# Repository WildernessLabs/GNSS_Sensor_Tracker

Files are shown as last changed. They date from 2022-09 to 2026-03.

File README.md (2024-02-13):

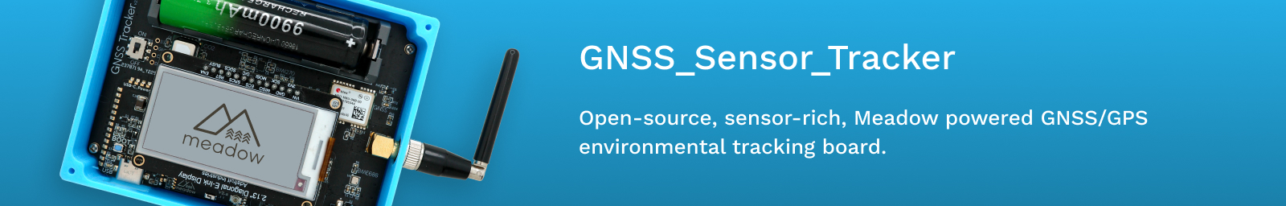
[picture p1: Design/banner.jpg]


# GNSS_Sensor_Tracker

The GNSS Sensor Tracker is an open-source, sensor-rich, GNSS/GPS tracking board intended to provide a base design accelerator for custom Meadow-based GNSS tracking solutions.

## Contents
* [Purchasing or Building](#purchasing-or-building)
* [Getting Started](#getting-started)
* [Hardware Specifications](#hardware-specifications)
* [Video Stream Design Series](#video-stream-design-series)
* [Industrial Enclosure Design](#industrial-enclosure-design)

## Purchasing or Building

<table width="100%">
    <tr>
        <td>
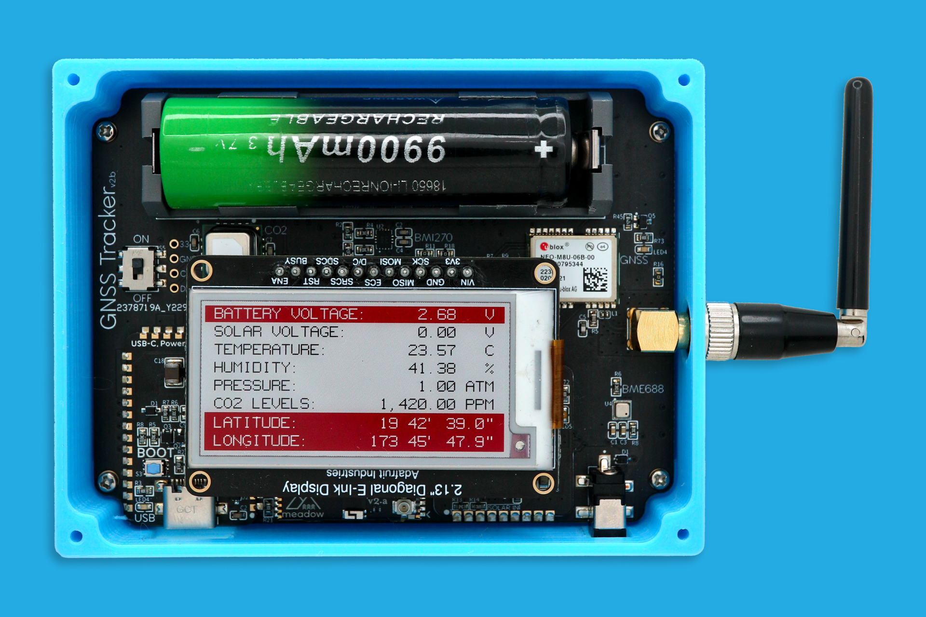
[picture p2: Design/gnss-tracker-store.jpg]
            
        </td>
        <td>
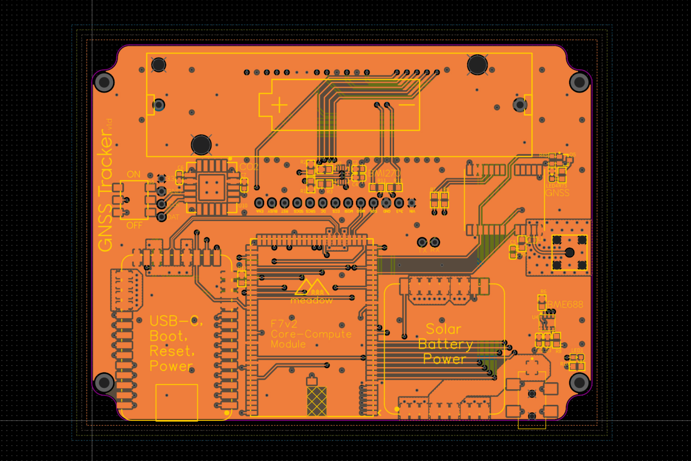
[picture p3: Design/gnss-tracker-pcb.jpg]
             
        </td>
    </tr>
    <tr>
        <td>
            You can get a Gnss Sensor Tracker fully assembled from the <a href="https://store.wildernesslabs.co/collections/frontpage/products/gnss-sensor-tracker">Wilderness Labs store</a>.
        </td>
        <td> 
            It's also designed so that it can be assembled at home for the adventurous. All design files can be found in the <a href="Hardware/Design%20Files/">Hardware Design</a> folder.
        </td>
    </tr>
</table>

## Getting Started

To simplify the way to use this Meadow-powered reference IoT product, we've created a NuGet package that instantiates and encapsulates the onboard hardware into a `GnssTracker` class.

1. Add the ProjectLab Nuget package your project: 
    - `dotnet add package Meadow.GnssTracker`, or
    - [Meadow.GnssTracker Nuget Package](https://www.nuget.org/packages/Meadow.GnssTracker)
    - [Explore in Fuget.org](https://www.fuget.org/packages/Meadow.GnssTracker/0.96.0/lib/netstandard2.1/GnssTracker.dll/WildernessLabs.Hardware.GnssTracker/GnssTracker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)

2. Instantiate the `IGnssTrackerHardware` object:  
```csharp
public class MeadowApp : App<F7CoreComputeV2>
{
    IGnssTrackerHardware gnssTracker;

    public override Task Initialize()
    {
        gnssTracker = GnssTracker.Create();
        ...
```

3. To Access the `GNSS Tracker` onboard peripherals (Display, for example):
```csharp
    if (gnssTracker.Display is { } display)
    {
        microGraphics = new MicroGraphics(display);
        microGraphics.Clear();
        microGraphics.DrawText(10, 10, "Hello World");
        microGraphics.Show();
    }
```

## Hardware Specifications

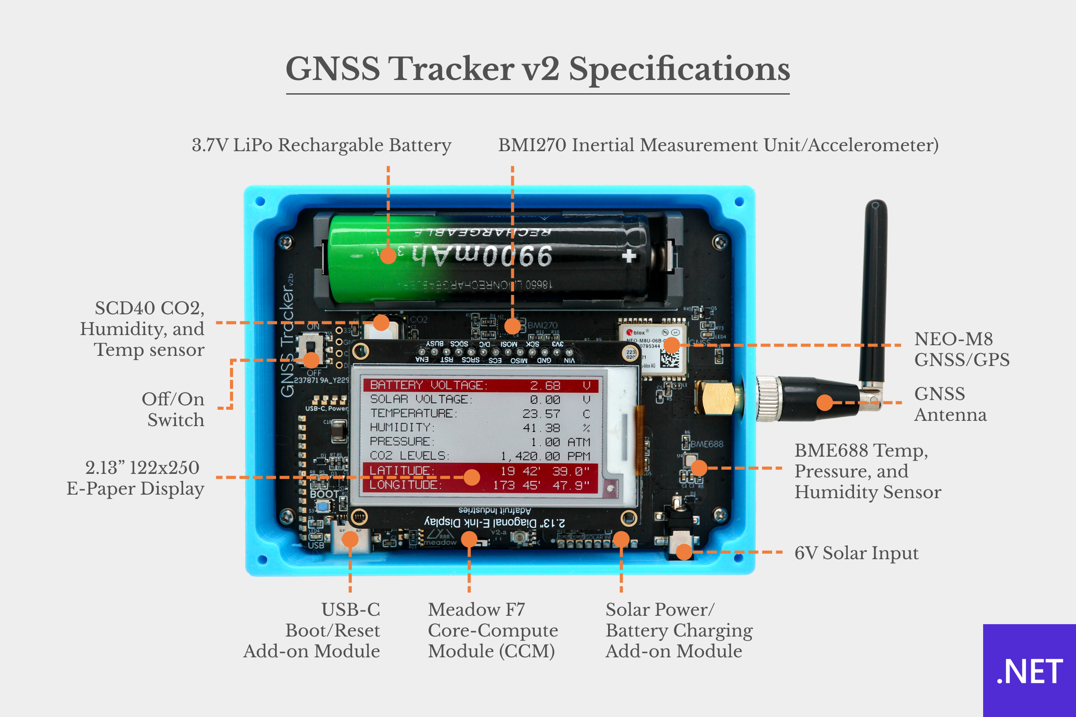
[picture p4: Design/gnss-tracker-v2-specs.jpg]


<table>
    <tr>
        <td><strong>3.7V LiPo Rechargeable Battery</strong></td>
        <td><strong>BMI270 Inertial Measurement Unit / Accelerometer</strong></td>
    </tr>
    <tr>
        <td><strong>SCD40 CO2, Humidity and Temperature sensor</strong></td>
        <td><strong>Off/On Switch</strong></td>
    </tr>
    <tr>
        <td><strong>SSD1680 122x250 Adafruit E-Paper Display</strong></td>
        <td><strong>USB-C, Boot, Reset Add-on Module</strong></td>
    </tr>
    <tr>
        <td><strong>Meadow F7 Core-Compute Module (CCM)</strong></td>
        <td><strong>Solar Power/Battery Charging Add-on Module</strong></td>
    </tr>
    <tr>
        <td><strong>6V Solar Input Connector</strong></td>
        <td><strong>BME688 Temp, Pressure and Humidity sensor</strong></td>
    </tr>
    <tr>
        <td><strong>GNSS/GPS Antenna</strong></td>
        <td><strong>NEO-M8 GNSS/GPS</strong></td>
    </tr>
</table>

You can find the schematics and other design files in the [Hardware folder](Hardware/Design%20Files/).

## Video Stream Design Series

This board was designed while streaming live, you can watch the videos [here](https://www.youtube.com/watch?v=L4MavM8ilkg&list=PLoP9Fu9zn7qY4rkFJjHBhnpI8mPlw8RfS).

<a href="https://www.youtube.com/watch?v=L4MavM8ilkg&list=PLoP9Fu9zn7qY4rkFJjHBhnpI8mPlw8RfS">
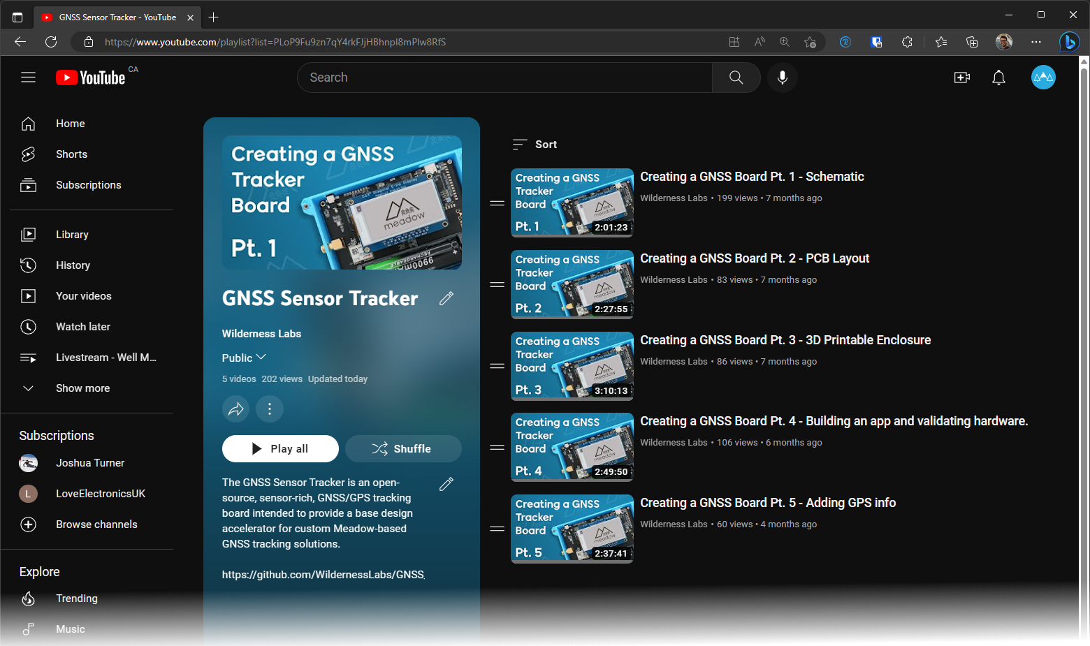
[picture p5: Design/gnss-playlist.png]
    
</a>

## Industrial Enclosure Design

The enclosure was designed in Autodesk Fusion 360. The source file can be found and STL files can be found [here](Hardware/Enclosure/).

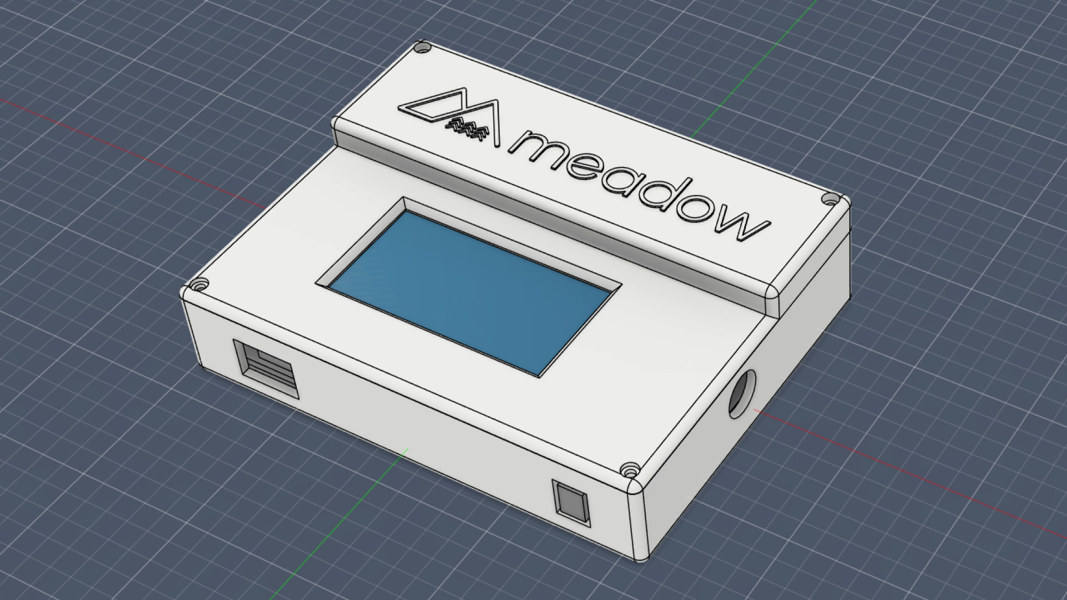
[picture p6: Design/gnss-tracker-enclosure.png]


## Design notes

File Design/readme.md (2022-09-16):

# Docs

This board was prototyped using the [Addon Modules](https://github.com/WildernessLabs/Hardware_Addon_Modules) we created to shorten hardware design time.

## Schematic 



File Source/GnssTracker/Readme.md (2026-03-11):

# Meadow.GnssTracker

**Convenience library for the Meadow GNSS Sensor Tracker**

The **GnssTracker** library is included in the **Meadow.GnssTracker** nuget package and is designed for the [Wilderness Labs](www.wildernesslabs.co) Meadow .NET IoT platform.

The GNSS Sensor Tracker is an open-source, sensor-rich, GNSS/GPS tracking board that provides a base design accelerator for custom Meadow-based GNSS tracking solutions.

For more information on developing for Meadow, visit [developer.wildernesslabs.co](http://developer.wildernesslabs.co/).

To view all Wilderness Labs open-source projects, including samples, visit [github.com/wildernesslabs](https://github.com/wildernesslabs/).

## Onboard Hardware

| Peripheral | Description |
|---|---|
| NEO-M8 | GNSS/GPS module with antenna connector |
| SSD1680 | 122x250 e-paper display |
| BME688 | Temperature, pressure, humidity, and gas resistance sensor |
| SCD40 | CO2, humidity, and temperature sensor |
| BMI270 | Inertial measurement unit / accelerometer |
| RGB LED | Onboard status LED |
| Solar input | 6V solar connector with battery charging |
| Battery | 3.7V LiPo rechargeable battery |

## Installation

You can install the library from within Visual Studio using the NuGet Package Manager or from the command line using the .NET CLI:

`dotnet add package Meadow.GnssTracker`

## Usage

```csharp
public class MeadowApp : App<F7CoreComputeV2>
{
    IGnssTrackerHardware gnssTracker;

    public override Task Initialize()
    {
        gnssTracker = GnssTracker.Create();

        if (gnssTracker.TemperatureSensor is { } temperatureSensor)
        {
            temperatureSensor.Updated += (s, e) =>
                Resolver.Log.Info($"Temperature: {e.New.Celsius:N1}C");
        }

        if (gnssTracker.Gnss is { } gnss)
        {
            gnss.RmcReceived += (s, e) =>
            {
                if (e.IsValid)
                    Resolver.Log.Info($"GNSS: LAT [{e.Position.Latitude}], LONG [{e.Position.Longitude}]");
            };
        }

        if (gnssTracker.Display is { } display)
        {
            var graphics = new MicroGraphics(display);
            graphics.DrawText(10, 10, "Hello, GNSS Tracker!");
            graphics.Show();
        }

        if (gnssTracker.OnboardRgbLed is { } led)
        {
            led.StartPulse(Color.Green);
        }

        return Task.CompletedTask;
    }

    public override async Task Run()
    {
        if (gnssTracker.TemperatureSensor is { } temperatureSensor)
            temperatureSensor.StartUpdating(TimeSpan.FromMinutes(5));

        if (gnssTracker.Gnss is { } gnss)
            gnss.StartUpdating();

        await Task.Delay(Timeout.Infinite);
    }
}
```

## How to Contribute

- **Found a bug?** [Report an issue](https://github.com/WildernessLabs/Meadow_Issues/issues)
- Have a **feature idea or driver request?** [Open a new feature request](https://github.com/WildernessLabs/Meadow_Issues/issues)
- Want to **contribute code?** Fork the [GNSS_Sensor_Tracker](https://github.com/WildernessLabs/GNSS_Sensor_Tracker) repository and submit a pull request against the `develop` branch

## Need Help?

If you have questions or need assistance, please join the Wilderness Labs [community on Slack](http://slackinvite.wildernesslabs.co/).

## About Meadow

Meadow is a complete, IoT platform with defense-grade security that runs full .NET applications on embeddable microcontrollers and Linux single-board computers including Raspberry Pi and NVIDIA Jetson.

### Build

Use the full .NET platform and tooling such as Visual Studio and plug-and-play hardware drivers to painlessly build IoT solutions.

### Connect

Utilize native support for WiFi, Ethernet, and Cellular connectivity to send sensor data to the Cloud and remotely control your peripherals.

### Deploy

Instantly deploy and manage your fleet in the cloud for OtA, health-monitoring, logs, command + control, and enterprise backend integrations.

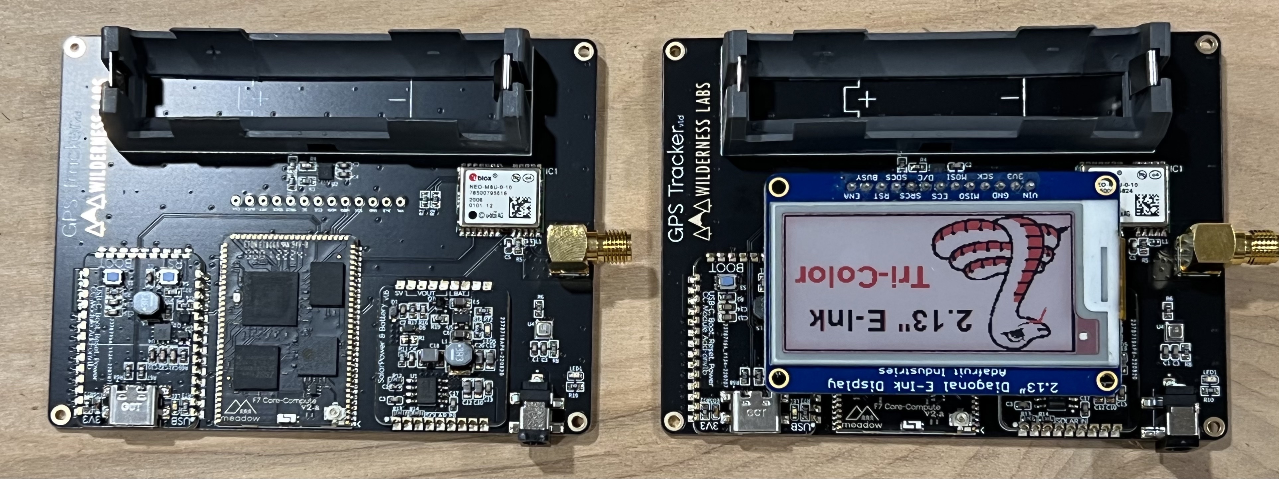
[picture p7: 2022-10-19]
Design/gnss-tracker-sides.jpg

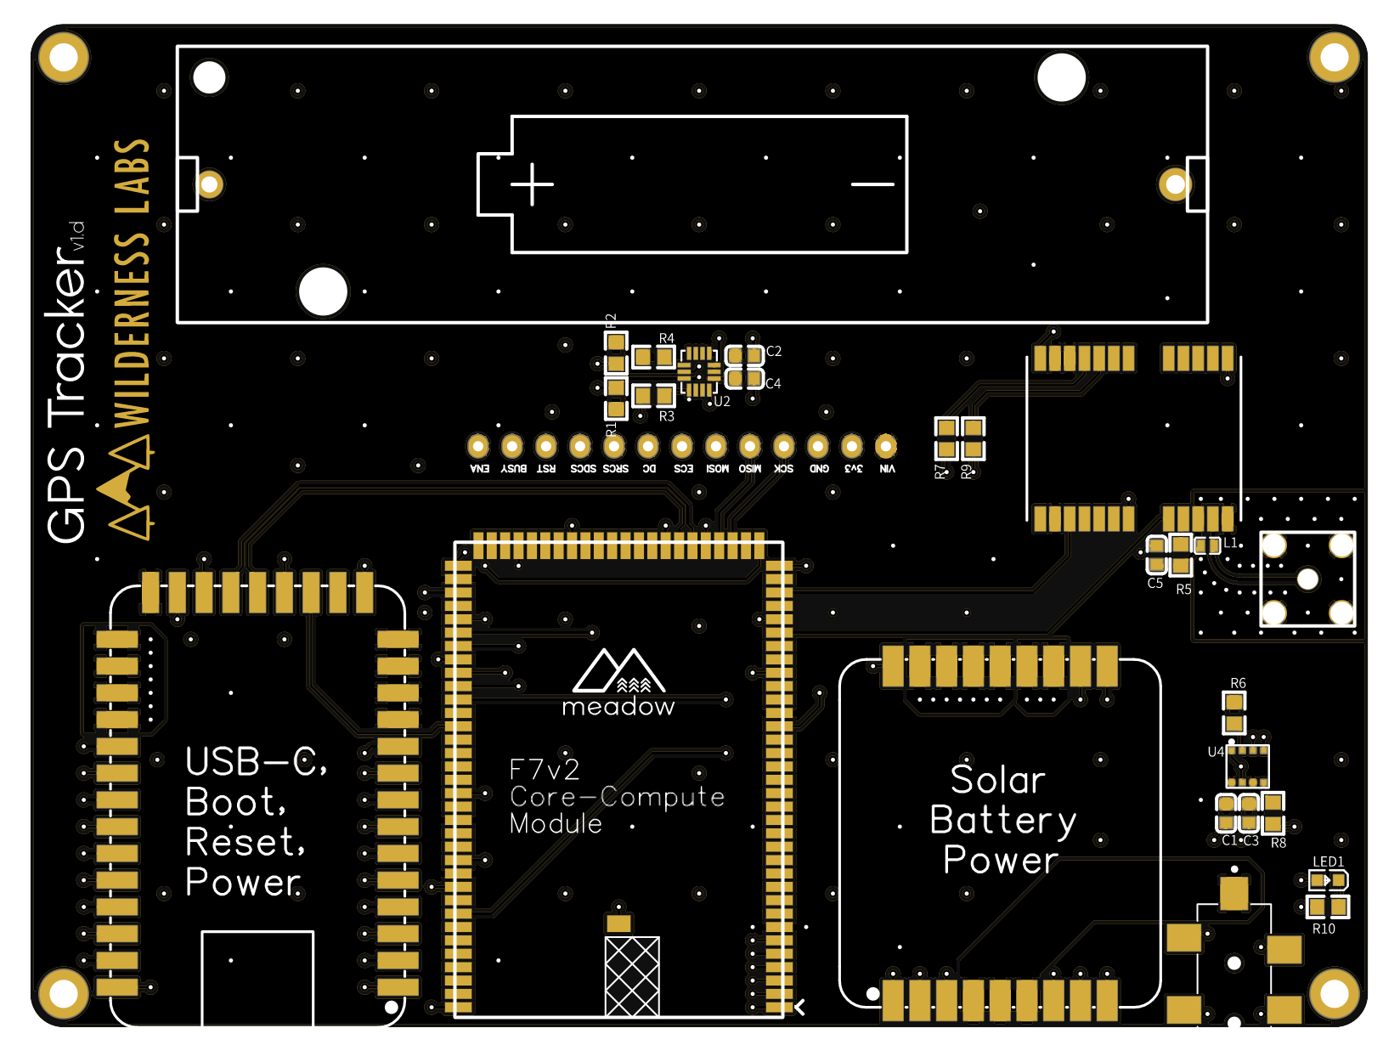
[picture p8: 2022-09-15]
Design/gnss-tracker-pcb-view.png

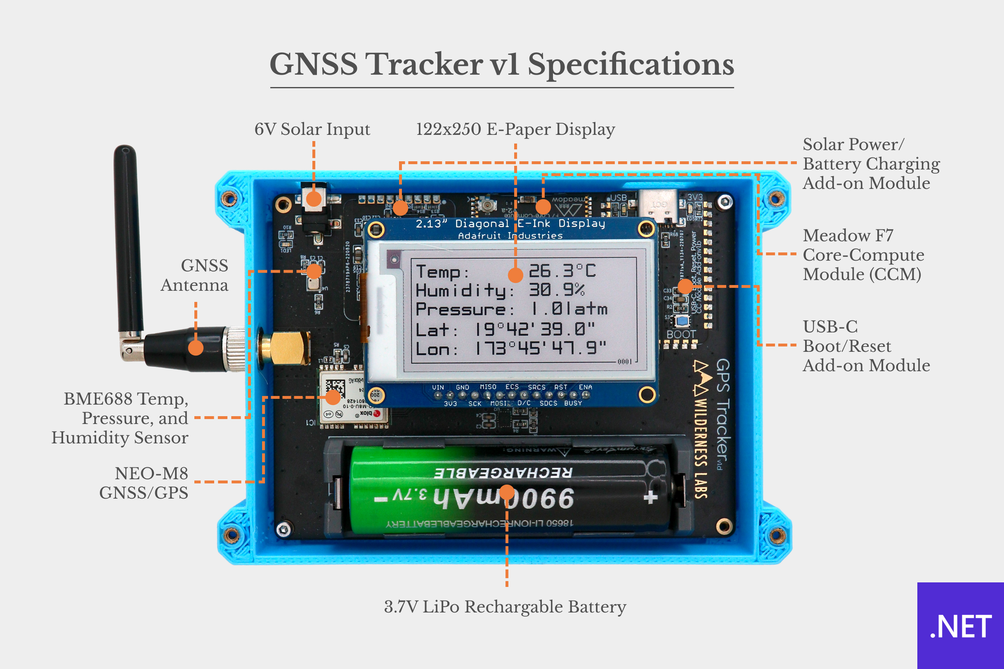
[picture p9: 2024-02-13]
Design/gnss-tracker-v1-specs.jpg

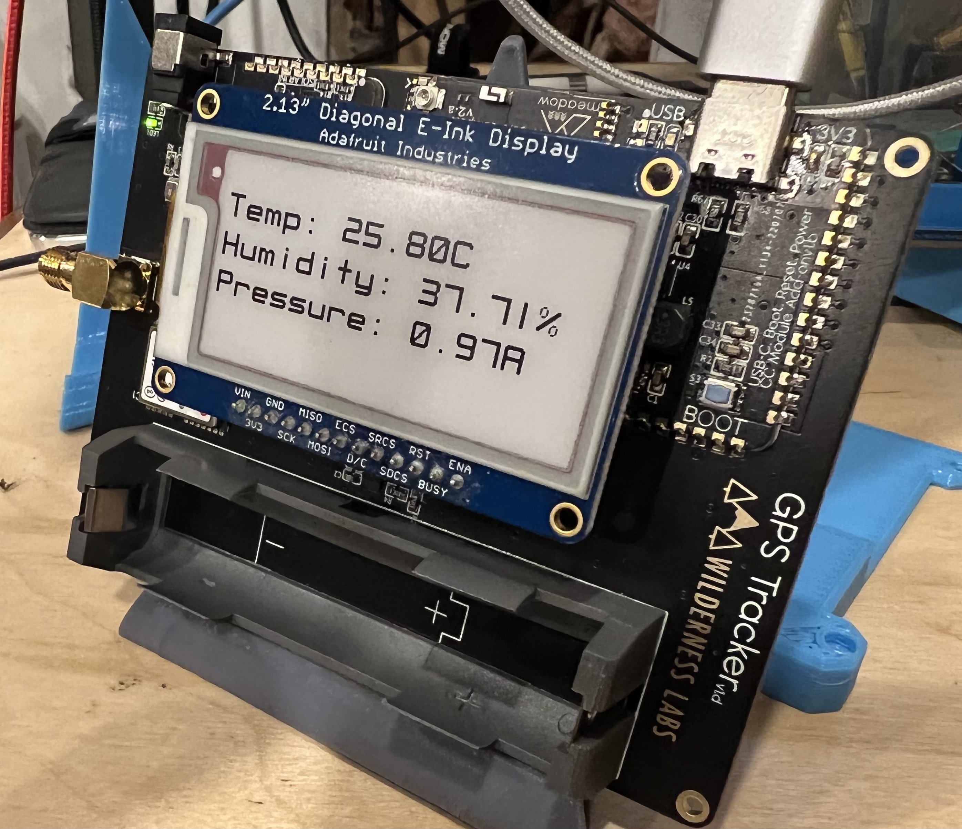
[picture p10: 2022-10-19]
Design/gnss-tracker-display.jpg

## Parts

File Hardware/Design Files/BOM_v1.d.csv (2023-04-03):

ID | Name | Designator | Footprint | Quantity | Manufacturer Part | Manufacturer | Supplier | Supplier Part | Price
1 | MEADOW F7 DEBUG ADDON MODULE | U15 | MEADOW F7 DEBUG ADDON MODULE | 1
2 | WILDERNESS_LABS_LOGO_HORIZONTAL | U9 | WILDERNESS_LABS_LOGO_HORIZONTAL | 1
3 | 0 | R12,R11,R18 | R0603 | 3 | RC0603JR-070RL | Yageo
4 | 1043P | U6 | BAT-TH_KEYSTONE-1043P | 1 | 1043P | Keystone | Digi-Key
5 | 452403012014 | S5 | 452403012014 | 1 | 452403012014 | Wurth Elektronik
6 | 470k | R45 | R0603 | 1 | RC0603FR-07470KL | Yageo
7 | EAST16083BA0 | LED4 | LED0603-RD | 1 | EAST16083BA0 | Everlight
8 | DMG1012UW-7 | Q5 | SOT-323-3_L2.2-W1.3-P1.30-LS2.1-BR | 1 | DMG1012UW-7 | Diodes Incorporated | LCSC | C156390 | 0.005
9 | 2k | R73,R10 | R0603 | 2 | RC0603FR-072KL | Yageo
10 | TESTPAD_PTH | TP1,TP2,TP3,TP4,TP5,TP6 | TESTPAD_PTH | 6
11 | 0.1u | C6,C7,C1,C2,C3,C4 | C0603 | 6 | CC0603KRX7R9BB103 | Yageo
12 | SCD40-D-R2 | U10 | LGA-20_L10.1-W10.1-P1.25-TL | 1 | SCD40-D-R2 | null | LCSC | C9900009940
13 | NEO-M8U | IC1 | NEO-M8U | 1
14 | ADAFRUIT_2.13_ePaper | U7 | ADAFRUIT 2.13 EINK 4197 (NO HOLES) | 1 | 4947 | Adafruit | Adafruit | 4947
15 | 47pF | C5 | C0603 | 1 | CC0603JRNPO9BN470 | Yageo
16 | PJ-030CH-SMT-TR | J1 | CUI_PJ-030CH-SMT-TR | 1
17 | 1kΩ | L1 | L0402 | 1 | BLM15HD102SN1D | MuRata | LCSC | C21516 | 0.001
18 | EAST1608GA0 | LED1 | LED0603-RD | 1 | EAST1608GA0 | Everlight
19 | 4.7k | R1,R2 | R0603 | 2 | RC0603JR-074K7L | Yageo
20 | 10k | R3,R4,R6,R8 | R0603 | 4 | RC0603FR-0710KL | Yageo
21 | 10Ω | R5 | R0603 | 1 | RC0603FR-0710RL | Yageo
22 | 220 | R7,R9 | R0603 | 2 | RC0603FR-07220RL | Yageo
23 | Meadow F7v2 Core-Compute Module - Logical | U1 | MEADOW_F7V2_CORE_COMPUTE | 1 |  | Wilderness Labs
24 | BMI270 | U2 | LGA-14_L3.0-W2.5-P0.50-BR | 1 | BMI270 | null | LCSC | C2836813 | 0.314
25 | Meadow Core-Compute USB-C, Power, Boot, and Reset Addon Module | U3 | MEADOW CORE-COMPUTE USB-C, POWER, BOOT, RESET ADDON MODULE | 1 |  | Wilderness Labs
26 | BME688 | U4 | LGA-8_L3.0-W3.0-P0.80-TR | 1 | BME688 | Bosch Sensortec
27 | 60311002114501 | U8 | SMA_60311002114501 | 1 | 60311002114501 | Wurth Elektronik | Adafruit
28 | Meadow Core-Compute Addon Module - Solar Battery Power | U5 | MEADOW CORE-COMPUTE SOLAR & BATTERY POWER ADDON MODULE | 1 |  | Wilderness Labs

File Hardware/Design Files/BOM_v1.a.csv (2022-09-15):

ID | Name | Designator | Footprint | Quantity | Manufacturer Part | Manufacturer | Supplier | Supplier Part | Price
1 | 0.1u | C1,C2,C3,C4 | C0603 | 4 | CC0603KRX7R9BB103 | Yageo
2 | 47pF | C5 | C0603 | 1 | CC0603JRNPO9BN470 | Yageo
3 | NEO-M8N | IC1 | NEO-M8U | 1
4 | PJ-030CH-SMT-TR | J1 | CUI_PJ-030CH-SMT-TR | 1
5 | 1kΩ | L1 | L0402 | 1 | BLM15HD102SN1D | MuRata | LCSC | C21516 | 0.009
6 | EAST1608GA0 | LED1 | LED0603-RD | 1 | EAST1608GA0 | Everlight
7 | 4.7k | R1,R2 | R0603 | 2 | RC0603JR-074K7L | Yageo
8 | 10k | R3,R4,R6,R8 | R0603 | 4 | RC0603FR-0710KL | Yageo
9 | 10Ω | R5 | R0603 | 1 | RC0603FR-0710RL | Yageo
10 | 220 | R7,R9 | R0603 | 2 | RC0603FR-07220RL | Yageo
11 | 2k | R10 | R0603 | 1 | RC0603FR-072KL | Yageo
12 | Meadow F7v2 Core-Compute Module - Logical | U1 | MEADOW_F7V2_CORE_COMPUTE | 1 |  | Wilderness Labs
13 | BMI270 | U2 | LGA-14_L3.0-W2.5-P0.50-BR | 1 | BMI270 | null | LCSC | C2836813 | 3.533
14 | Meadow Core-Compute USB-C, Power, Boot, and Reset Addon Module | U3 | MEADOW CORE-COMPUTE USB-C, POWER, BOOT, RESET ADDON MODULE | 1 |  | Wilderness Labs
15 | BME688 | U4 | LGA-8_L3.0-W3.0-P0.80-TR | 1 | BME688 | Bosch Sensortec
16 | Meadow Core-Compute Addon Module - Solar Battery Power | U5 | MEADOW CORE-COMPUTE SOLAR & BATTERY POWER ADDON MODULE | 1 |  | Wilderness Labs
17 | 1043P | U6 | BAT-TH_KEYSTONE-1043P | 1 | 1043P | Keystone | Digi-Key
18 | ADAFRUIT_2.13_ePaper | U7 | ADAFRUIT 2.13 EINK 4197 (NO HOLES) | 1 | 4947 | Adafruit | Adafruit | 4947
19 | 60311002114501 | U8 | SMA_60311002114501 | 1 | 60311002114501 | Wurth Elektronik | Adafruit
20 | WILDERNESS_LABS_LOGO_HORIZONTAL | U9 | WILDERNESS_LABS_LOGO_HORIZONTAL | 1

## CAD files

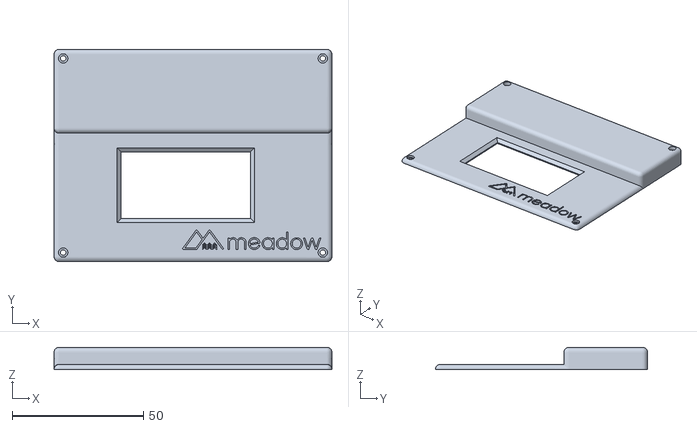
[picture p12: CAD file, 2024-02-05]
Hardware/Enclosure/GNSS_Enclosure_Top.stl
106.0 x 81.0 x 8.50

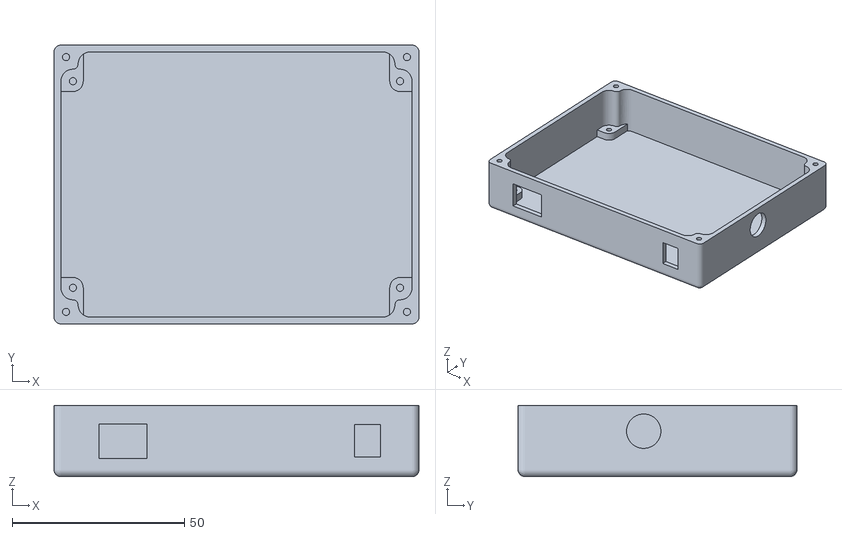
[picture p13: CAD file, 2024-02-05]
Hardware/Enclosure/GNSS_Enclosure_Bottom.stl
106.0 x 81.0 x 20.7

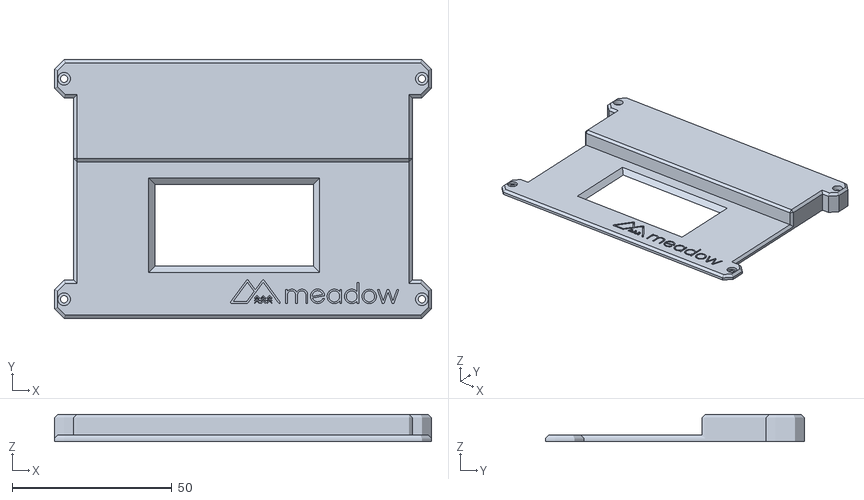
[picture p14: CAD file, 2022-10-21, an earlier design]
Hardware/Enclosure/Legacy/GNSS_Enclosure_Top.stl
118.0 x 81.0 x 8.50

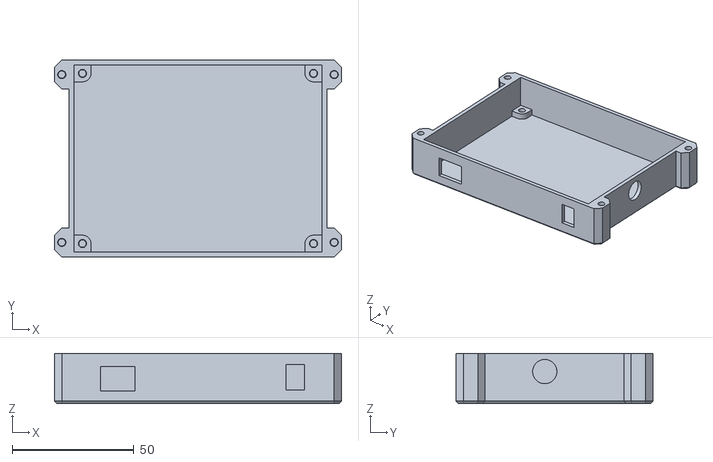
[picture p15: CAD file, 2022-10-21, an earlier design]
Hardware/Enclosure/Legacy/GNSS_Enclosure_Bottom.stl
118.0 x 81.0 x 20.7

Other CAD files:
Hardware/Enclosure/GNSS Sensor Tracker - Enclosure.f3d
Hardware/Enclosure/GNSS_Tracker_Enclosure.f3d
Hardware/Enclosure/Legacy/GNSS_Tracker_Enclosure.f3d

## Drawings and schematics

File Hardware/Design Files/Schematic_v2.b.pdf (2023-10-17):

## 0x77 - VDD

## 0x76 - GND

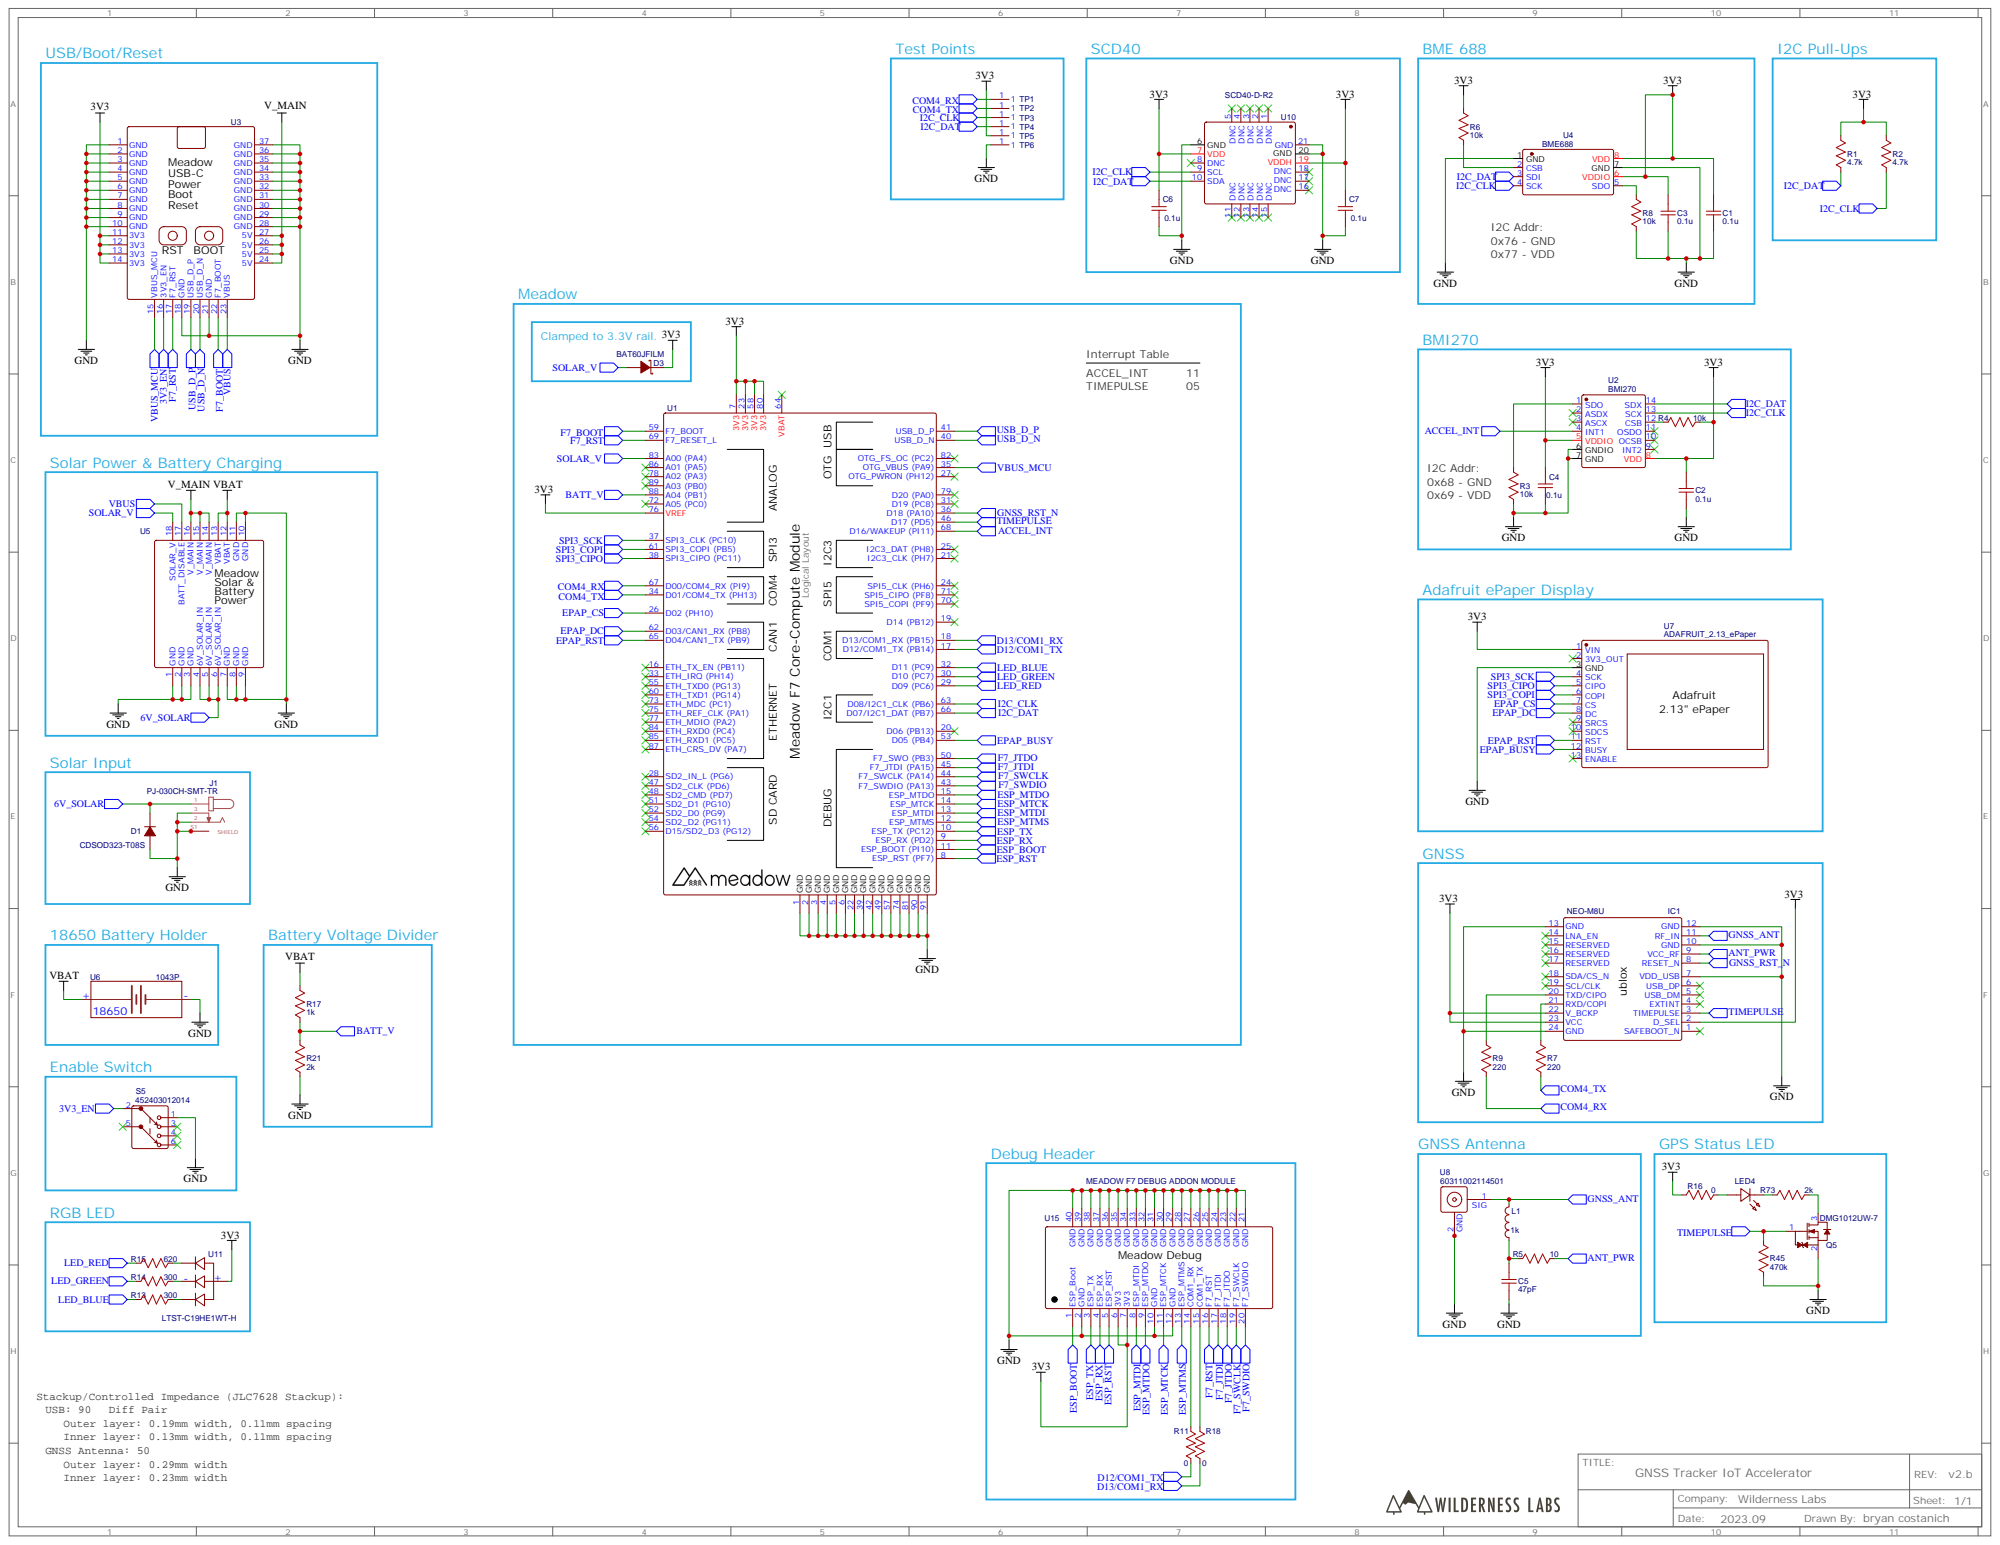
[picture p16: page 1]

5V 24 5V 25 5V 26 5V 27 GND 28 GND 29 GND 30 GND 31 GND 32 GND 33 GND 34 GND 35 GND 36 GND 37

Solar Power & Battery Charging

Meadow F7 Core-Compute Module

9 GND 10 GND 11 VBAT 12 VBAT 13 V_MAIN 14 V_MAIN 15 V_MAIN 16 BATT_DISABLE 17 SOLAR_V 18

MEADOW F7 DEBUG ADDON MODULE

F7_SWDIO 20 GND 21 GND 22 GND 23 GND 24 GND 25 GND 26 GND 27 GND 28 GND 29 GND 30 GND 31 GND 32 GND 33 GND 34 GND 35 GND 36 GND 37 GND 38 GND 39 GND 40

Stackup/Controlled Impedance (JLC7628 Stackup):
Outer layer: 0.19mm width, 0.11mm spacing
Inner layer: 0.13mm width, 0.11mm spacing
GNSS Antenna: 50
Outer layer: 0.29mm width
Inner layer: 0.23mm width

Drawn By: bryan costanich

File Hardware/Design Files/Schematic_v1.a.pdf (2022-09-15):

## 0x77 - VDD

## 0x76 - GND

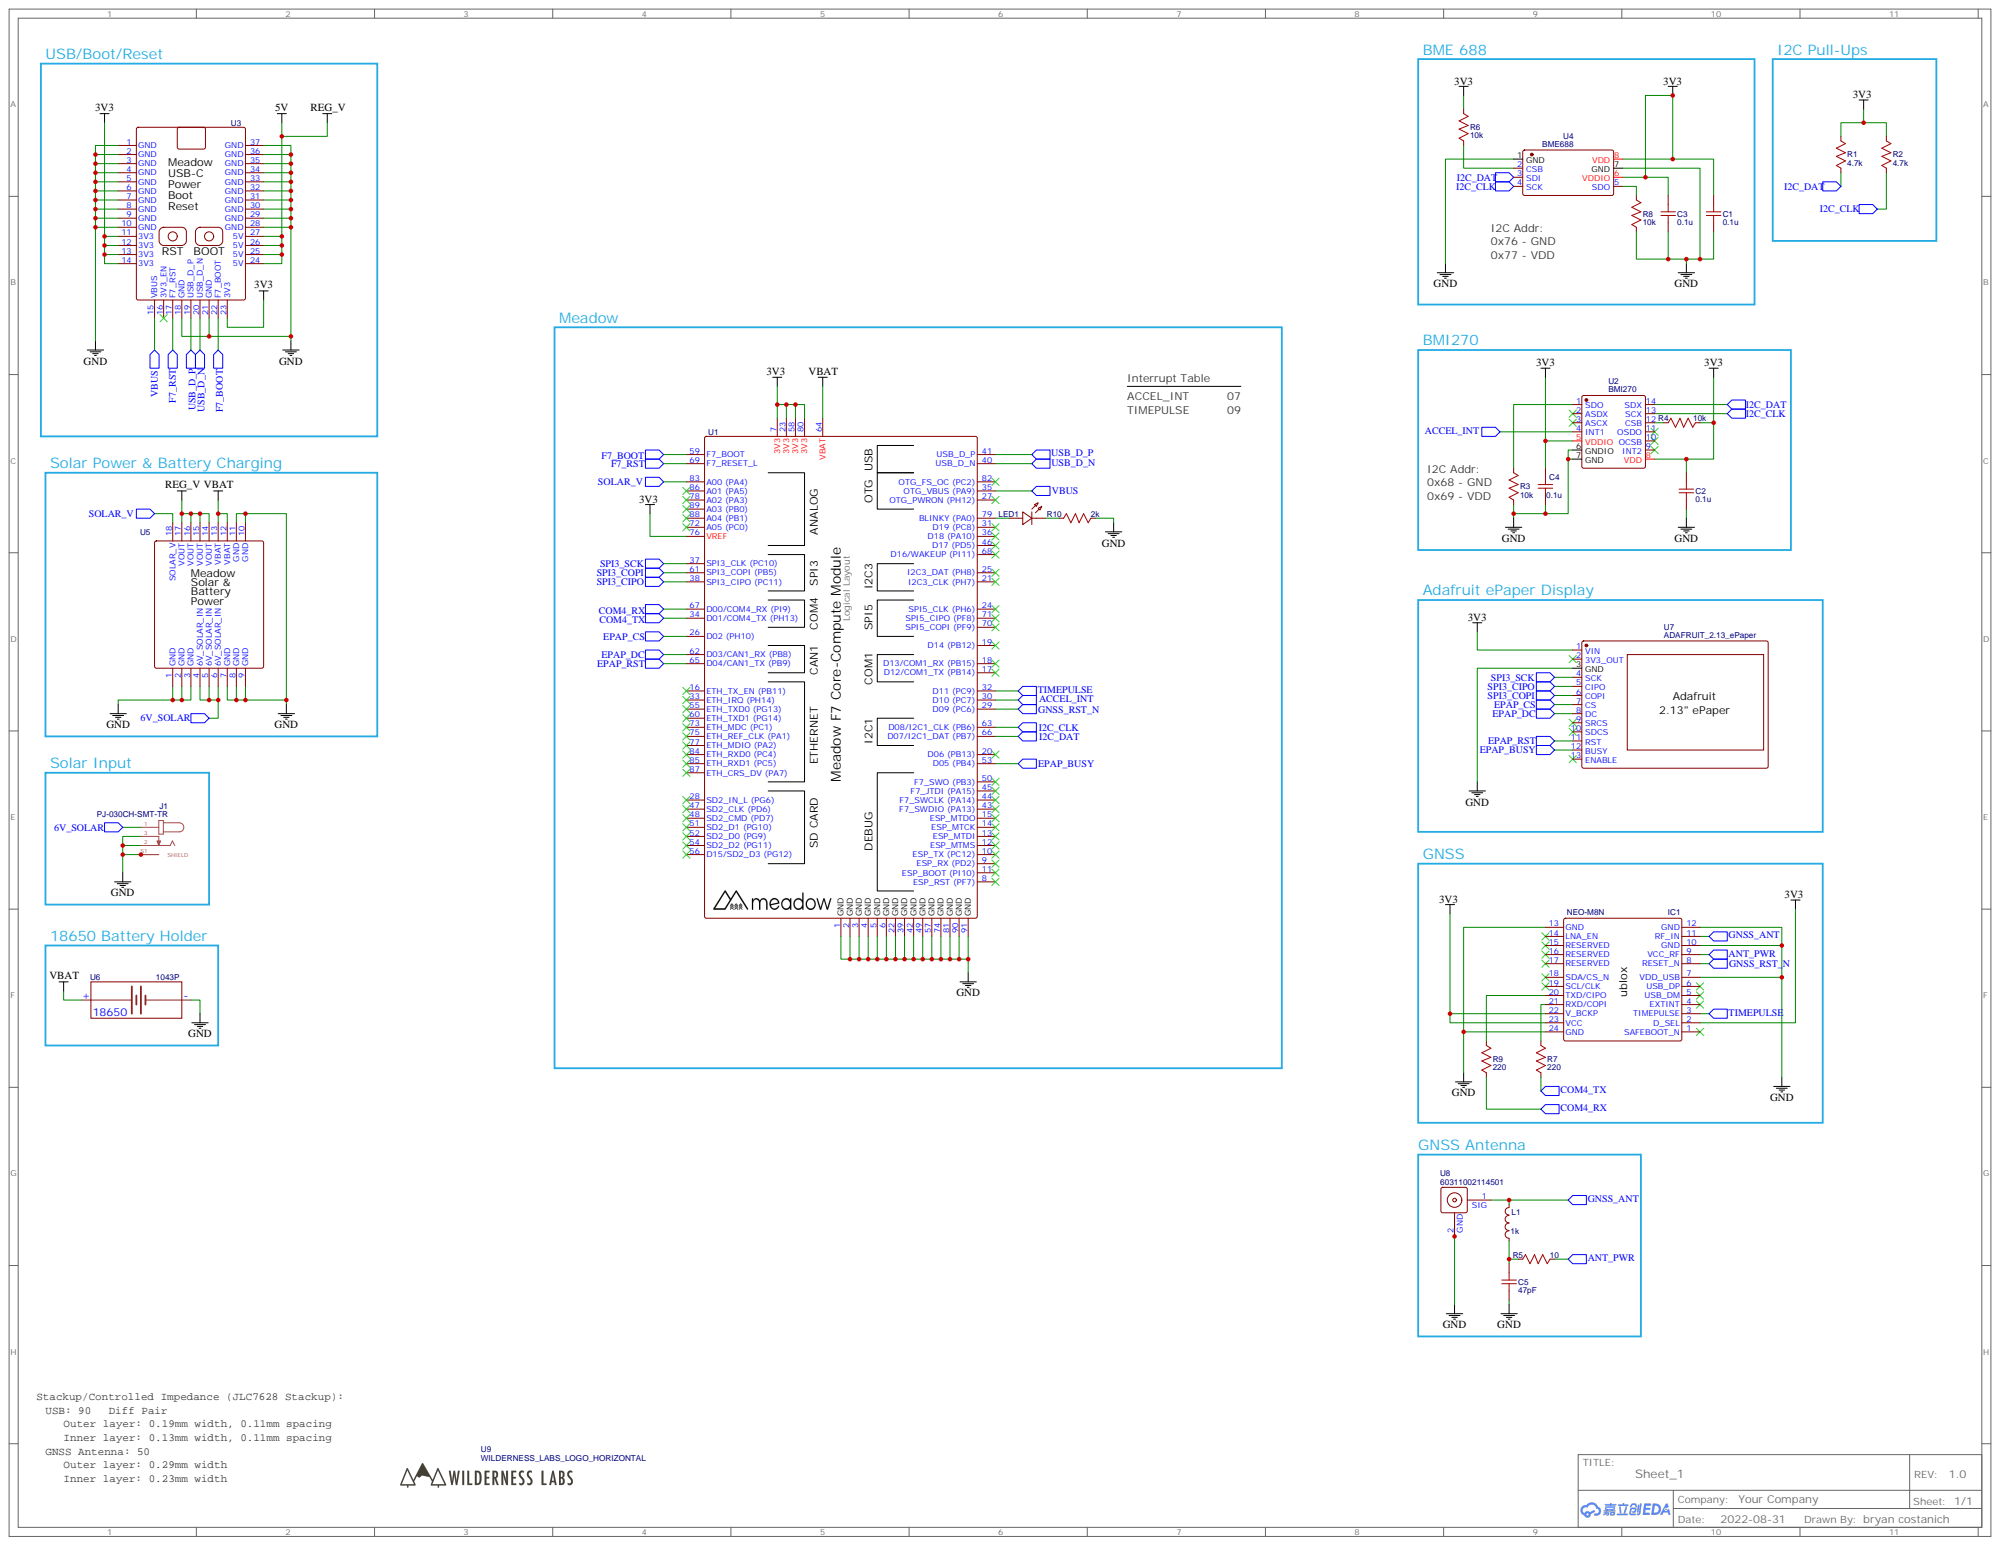
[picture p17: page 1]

REG_V
5V 24 5V 25 5V 26 5V 27 GND 28 GND 29 GND 30 GND 31 GND 32 GND 33 GND 34 GND 35 GND 36 GND 37

Solar Power & Battery Charging

9 GND 10 GND 11 VBAT 12 VBAT 13 VOUT 14 VOUT 15 VOUT 16 VOUT 17 SOLAR_V 18

Meadow F7 Core-Compute Module

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

Drawn By: bryan costanich

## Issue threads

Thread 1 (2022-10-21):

Hardware Enhancement: CO2 sensor

bryancostanich, 2022-10-21:
Add SCD-40 CO2 sensor

bryancostanich, 2023-08-28:
fixed in v1.x

Closed 2023-08-28.

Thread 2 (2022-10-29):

Hardware Enhancement: Add Status LED to GPS Receiver

bryancostanich, 2022-10-29:
The GNSS 10 click board has a GPS status LED driven by the `timepulse` pin. Seems useful, but may be problematic from a battery consumption perspective. maybe install a `0Ω` resistor as an optional feature.

bryancostanich, 2023-08-28:
fixed in v1.c? added 0Ω resistor in v2.a

Closed 2023-08-28.

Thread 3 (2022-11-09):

Hardware Enhancement: Add probe points

adrianstevens, 2022-11-09:
Expose pins or some other physical connection to make it easier to probe the serial lines, would be great to include 3.3v and ground.

bryancostanich, 2023-08-28:
fixed in v1.x

Closed 2023-08-28.

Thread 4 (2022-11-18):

Update board silk screen to "GNSS Sensor Tracker"

adrianstevens, 2022-11-18:
My current hardware shows "GPS Tracker"

If there's room, it's probably worth aligning the naming across the repo and the hardware

bryancostanich, 2023-08-28:
fixed in v1.x

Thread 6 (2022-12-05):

Hardware Enhancement: Add enable switch

bryancostanich, 2022-12-05:
to turn the whole thing on/off

bryancostanich, 2023-08-28:
fixed in v1.x

Closed 2023-08-28.

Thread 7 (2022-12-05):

Hardware Enhancement: Add diodes after USB/Boot/Reset to prevent battery from running LEDs

bryancostanich, 2022-12-05:
Currently, when on battery power, the LEDs on the USB/Boot/Reset board will light up. This drains power unnecessarily. Should add diodes to prevent this.

bryancostanich, 2023-08-28:
done in v1.b

Closed 2023-08-28.

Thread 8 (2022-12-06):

Add reset button header

adrianstevens, 2022-12-06:
Add headers so we add a button to the 3d printed case and reset the device

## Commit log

2022-09-15 Initial check in
    [BOM_v1.a.csv, GNSS_Enclosure_Bottom.stl, GNSS_Enclosure_Top.stl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]
2022-10-19 Updated bottom to fit antenna pth
    [GNSS_Enclosure_Bottom.stl, GNSS_Tracker_Enclosure.f3d]
2022-10-21 Fixed up enclosure
    Got cutouts aligned better, add meadow logo, sized up the print better, etc.
    [GNSS_Enclosure_Bottom.stl, GNSS_Enclosure_Top.stl, GNSS_Tracker_Enclosure.f3d]
2022-11-13 change to using M8 driver
2022-12-04 Setting device time from SPAAAAACE
    date time was just from the build before, but now it gets it from SPAAAAAAACE.
2022-12-12 Fix pressure in the atmospheric model
2023-03-06 Reorg repo folder structure
    [BOM_v1.a.csv, GNSS_Enclosure_Bottom.stl, GNSS_Enclosure_Top.stl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]
2023-04-03 Update schematics and BOM
    [BOM_v1.d.csv]
2023-04-21 Re-org folder structure
    [BOM_v1.a.csv, BOM_v1.d.csv, GNSS_Enclosure_Bottom.stl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]
2023-08-23 Cleanup and add Solar Voltage Input
2023-08-23 Update Demo samples
2023-09-25 Update Samples with Navigation
2023-10-18 Add connectors
2023-10-18 Reduce decimal places on temp and humidity to represent sensor accuracy
2024-01-02 Fix sample
2024-02-05 Update 3D printable enclosures
    [GNSS Sensor Tracker - Enclosure.f3d, GNSS_Enclosure_Bottom.stl, GNSS_Enclosure_Top.stl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]
2024-02-08 Add Battery Voltage Input
2024-02-09 Refactor GNSS Tracker (splitting sensors and use SensorService)
2024-02-20 Cleanup on SCD40 and BMI270 sensor
2024-02-21 Add convertion to Battery and Solar voltages
2024-05-07 changing to a more reasonable update period for a battery driven device.
2025-05-05 Update temperature interface
